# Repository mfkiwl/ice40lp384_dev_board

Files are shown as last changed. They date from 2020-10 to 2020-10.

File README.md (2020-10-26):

The ice30lp384_dev_board project is a multi-purpose castellated board that can be used in a breadboard or as a module in other projects.

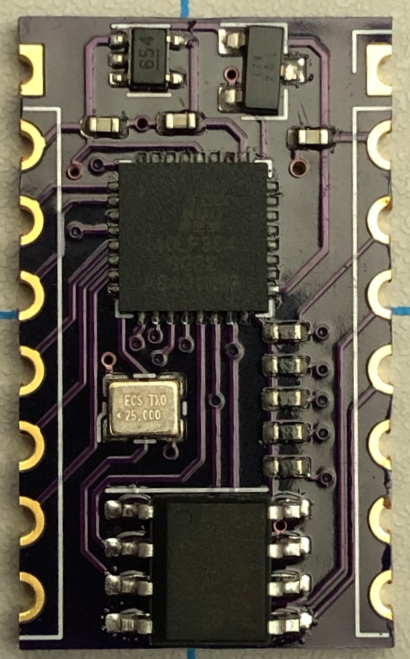
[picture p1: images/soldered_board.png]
main


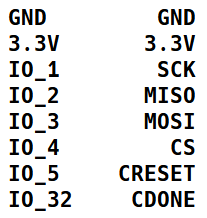
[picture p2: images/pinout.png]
pinout


- [Programming](/docs/Programming.md)
- [Board Creation](/docs/Board_Creation.md)

The pins on the right side of the board are geared towards programming and the pins on the left are for general use.

PCBs were ordered from OSHPark.
Stencil was ordered from OSHStencil.
Parts were ordered from Mouser, see [BOM](/docs/BOM%20-Mouser%20.xlsx).

The constraint files can be found [here](/verilog_projects/config).

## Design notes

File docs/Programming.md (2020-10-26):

To program the SPI Flash you need to hold the FPGA in reset when powering up the board. To do this, you need to connect CRESET to GND. You can install a button or switch if you plan to do this often or just use a jumper wire.

Here is an example setup using a push-button connected to CRESET.
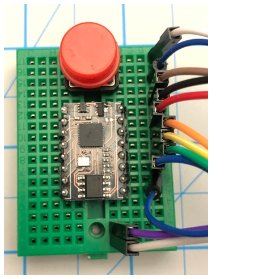
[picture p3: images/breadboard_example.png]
Breadboard Example


I use a [SPIDriver](https://spidriver.com/) to program the SPI Flash. There are dozens of alternative options. If you are on Linux then check out the [Flashrom supported programmers](https://flashrom.org/Supported_programmers).

A minimal programming connection needs the following lines hooked-up:

- GND to GND
- 3.3V to 3.3V
- SCK to SCK
- MISO to MISO
- MOSI to MOSI
- CS to CS
- CRESET to GND

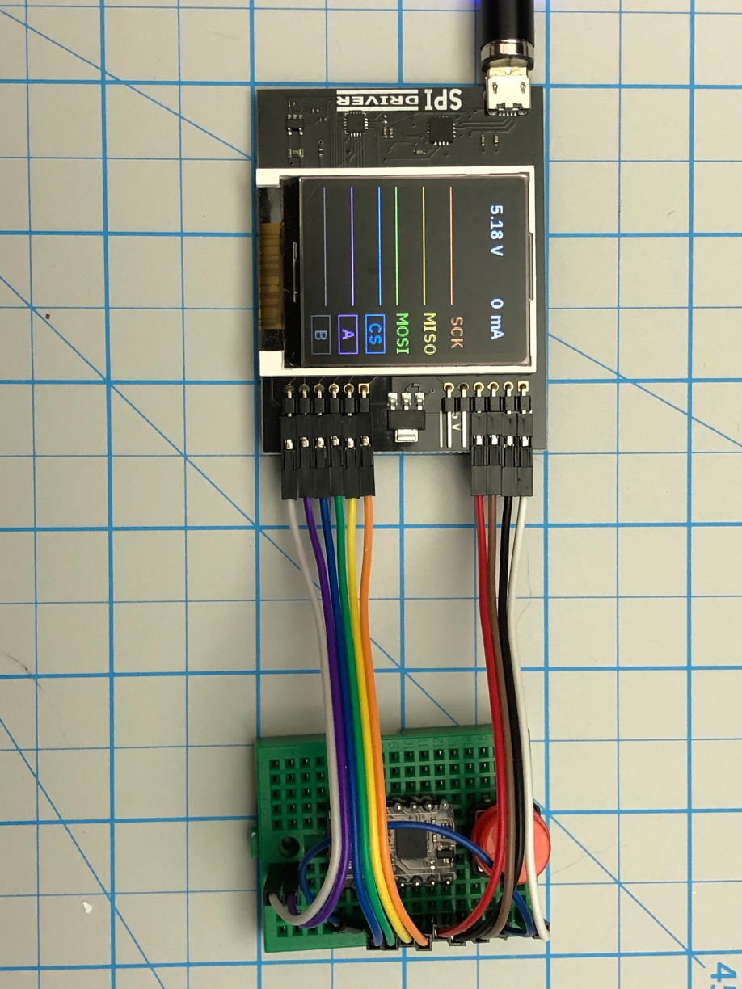
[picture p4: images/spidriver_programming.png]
SPIDriver Programming


Useful SPIDriver Commands:
```
# Read JEDEC
python flash.py -h COM3

# Write BIN file
python flash.py -h COM3 -w data\main_bitmap.bin
```

Programming with flashrom command on linux:
```
# Pad a file to 128k to match the size of the flash
tr '\0' '\377' < /dev/zero | dd bs=1 count=131072 of=image.bin

# Combine bitmap and padded file
dd if=blinky_bitmap.bin conv=notrunc of=image.bin

# Write padded bitmap file to SPI Flash
sudo flashrom -p ft2232_spi:type=232H -w image.bin
```

Note: Configuring the FPGA logic and setting up a develpment environment is outside the scope of this project. I recommend [NandLand](https://www.nandland.com/) for a great general purpose development board and in-depth tutorials if you are new to FPGAs. If you end up using IceCube2 with this board then make sure you [configure the project](/images/new_project_config.png) appropriately.

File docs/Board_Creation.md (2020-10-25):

# Board Creation

### PCB Front
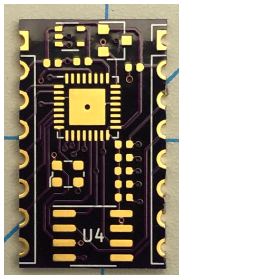
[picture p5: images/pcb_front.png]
PCB Front


### PCB Back
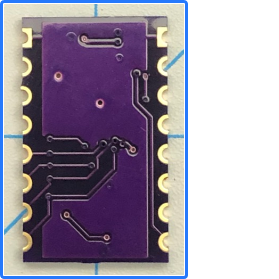
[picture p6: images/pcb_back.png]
PCB Back


### Stencil Alignment
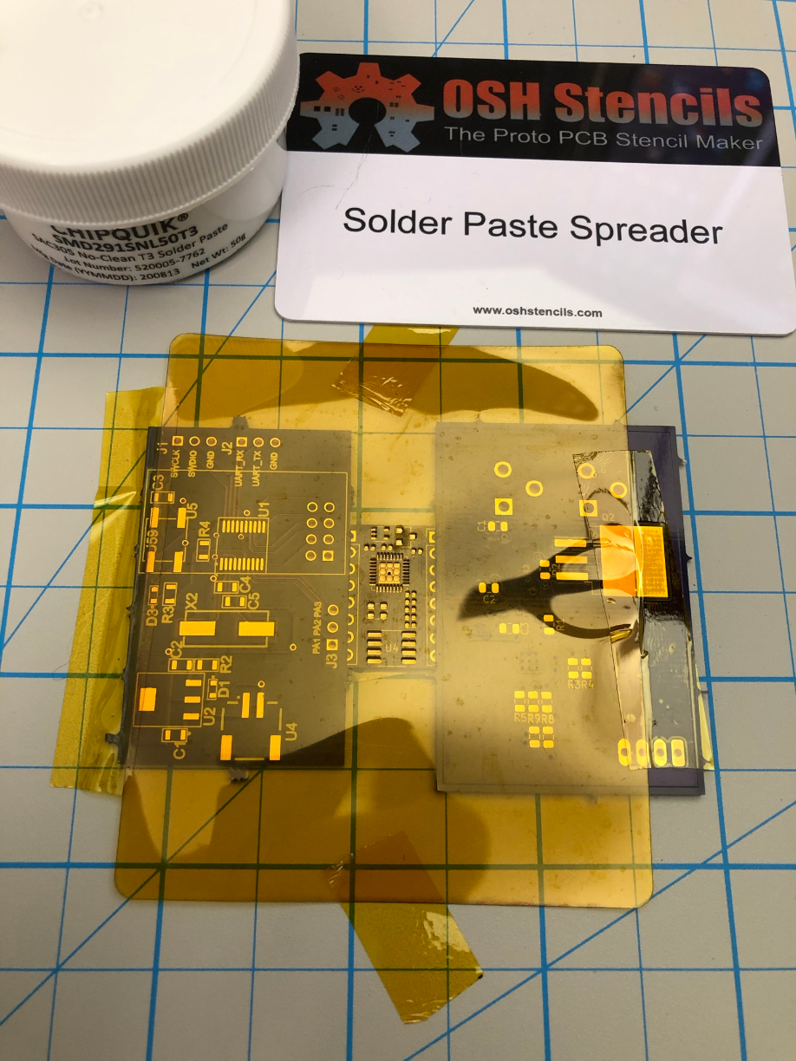
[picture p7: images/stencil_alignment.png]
Stencil Alignment


### Solder Paste
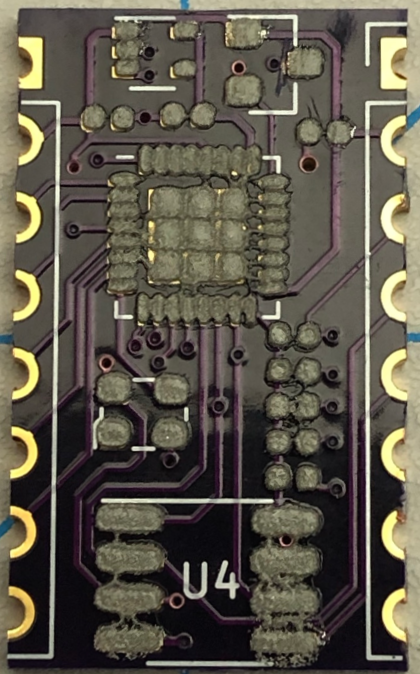
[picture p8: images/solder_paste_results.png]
Solder Paste Results


### Part Placement
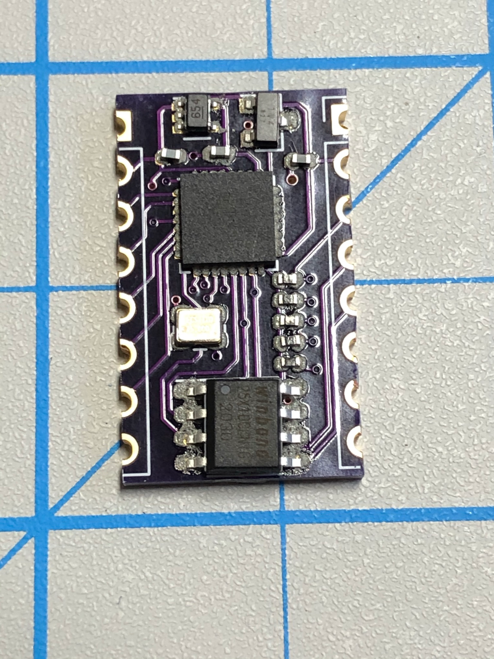
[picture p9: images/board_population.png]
Part Placement


### Reflow using Hot Plate. 
I use a cast iron skillet on a Hot Plate. Set the temperature dial to medium and remove boards when solder has melted ~5 mins.
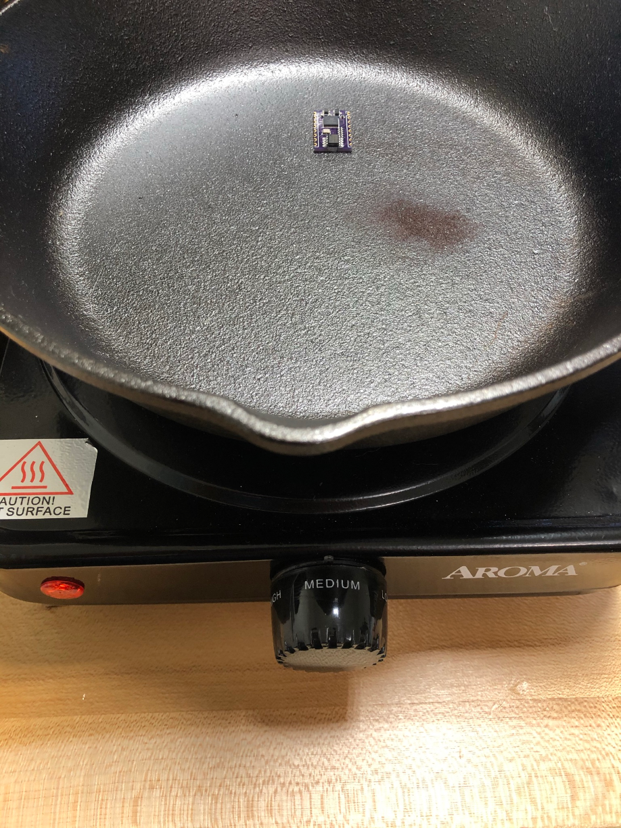
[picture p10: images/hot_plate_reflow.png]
Hot Plate Reflow


### Soldered Board
Soldered Board

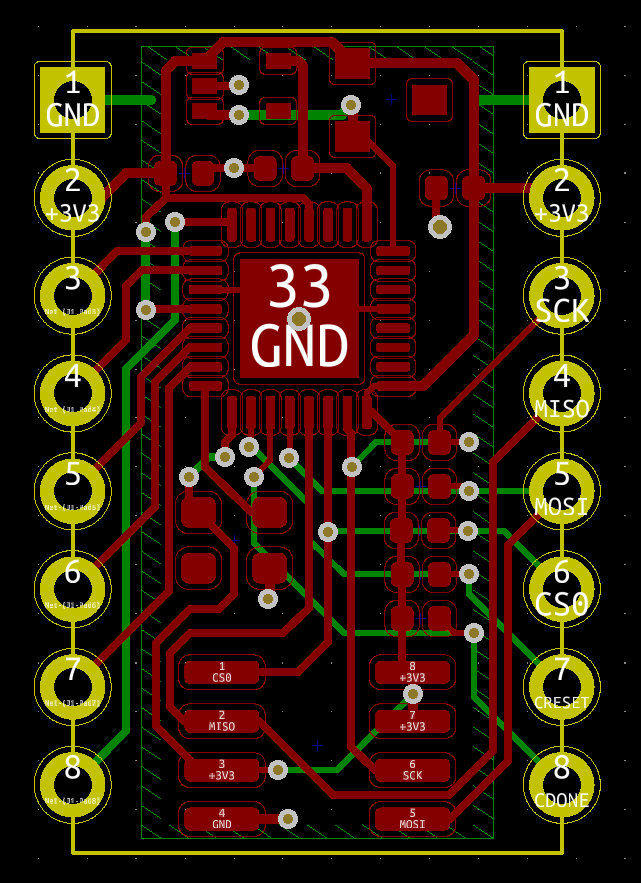
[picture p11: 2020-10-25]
images/layout_high_level.png

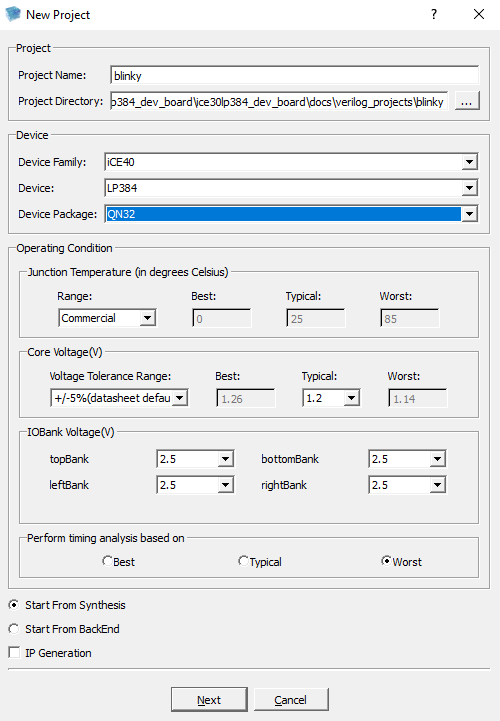
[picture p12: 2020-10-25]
images/new_project_config.png

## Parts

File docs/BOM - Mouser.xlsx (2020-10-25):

Mfr Part Number (Input) | Quantity 1 | Mfr Part Number | Mouser Part Number | Manufacturer Name | Description | Unit Price 1 | Order Quantity | Order Unit Price | Min./Mult. | Availability | Lead Time in Days | Lead Time in Weeks | Lifecycle | NCNR | RoHS | Pb Free | Package Type | Package Quantity | Datasheet URL | Product Image | Design Risk
998-MIC5365-1.2YC5TR | 1 | MIC5365-1.2YC5-TR | 998-MIC5365-1.2YC5TR | Microchip | LDO Voltage Regulators LDO Voltage Regulators Ultra Small Single 150mA LDO | $0.12 | 1 | $0.12 | 1\1 | 13,269 | 56 | 8 |  | No | Yes | Yes | REEL | 3,000 | https://www.mouser.com/datasheet/2/268/mic5365-1082359.pdf |  | Product has high popularity and is readily available.
757-TBAT54SLM | 1 | TBAT54S,LM | 757-TBAT54SLM | Toshiba | Schottky Diodes & Rectifiers Schottky Diodes & Rectifiers Small-Signal Schotky 0.2A 30V | $0.21 | 1 | $0.21 | 1\1 | 5,175 | 77 | 11 |  | No | Yes | Yes | REEL | 3,000 | https://toshiba.semicon-storage.com/info/docget.jsp?did=66549&prodName=TBAT54S |  | Product has high popularity and is readily available.
842-ICE40LP384SG32 | 1 | ICE40LP384-SG32 | 842-ICE40LP384SG32 | Lattice | FPGA - Field Programmable Gate Array FPGA - Field Programmable Gate Array iCE40LP Ultra LowPwr 384 LUTs 1.2V | $1.51 | 1 | $1.51 | 1\1 | 1,364 | 45 | 7 |  | No | Yes | Yes | TRAY | 490 | https://www.mouser.com/datasheet/2/225/FPGA-DS-02029-3-5-iCE40-LP-HX-Family-Data-Sheet-1022803.pdf |  | Product has high popularity and is readily available.
454-W25X10CLSNIG | 1 | W25X10CLSNIG | 454-W25X10CLSNIG | Winbond | NOR Flash NOR Flash spiFlash, 1M-bit, 4Kb Uniform Sector | $0.31 | 1 | $0.31 | 1\1 | 5,438 | 30 | 5 |  | No | Yes | Yes | TUBE | 2,000 | https://www.mouser.com/datasheet/2/949/w25x10cl_revg_021714-1489755.pdf |  | Product has high popularity and is readily available.
963-EMK105BJ105MVHF | 3 | EMK105BJ105MVHF | 963-EMK105BJ105MVHF | Taiyo Yuden | Multilayer Ceramic Capacitors MLCC - SMD/SMT Multilayer Ceramic Capacitors MLCC - SMD/SMT 0402 16VDC 1uF 20% X5R AEC-Q200 | $0.10 | 3 | $0.10 | 1\1 | 57,265 | 112 | 16 | New Product | No | Yes | Yes | REEL | 10,000 | https://www.mouser.com/datasheet/2/396/taiyo_yuden_12132018_mlcc11_hq_e-1510082.pdf |  | Product is new and is readily available.
603-RC0402FR-0710KL | 5 | RC0402FR-0710KL | 603-RC0402FR-0710KL | Yageo | Thick Film Resistors - SMD Thick Film Resistors - SMD 10K OHM 1% | $0.10 | 5 | $0.10 | 1\1 | 23,214,044 | 161 | 23 |  | No | Yes | No | REEL | 10,000 | https://www.mouser.com/catalog/additional/Yageo_6012_CM_Statement.pdf |  | Product has high popularity and is readily available.
538-22-28-4080 | 1 | 22-28-4080 | 538-22-28-4080 | Molex | Headers & Wire Housings Headers & Wire Housings 8P VERT HEADER Sn | $0.35 | 1 | $0.35 | 1\1 | 2,976 | 28 | 4 |  | No | Yes | Yes | BULK | 6,000 | https://www.mouser.com/catalog/additional/Molex.pdf |  | Product has high popularity and is readily available.
520-2520MV-250-BN-T | 1 | ECS-2520MV-250-BN-TR | 520-2520MV-250-BN-T | ECS | Standard Clock Oscillators Standard Clock Oscillators 25MHz 1.6-3.6V -40C +85C | $0.96 | 1 | $0.96 | 1\1 | 3,019 | 84 | 12 |  | No | Yes | Yes | REEL | 3,000 | https://www.mouser.com/datasheet/2/122/ECS-2520MV-1314080.pdf |  | Product has high popularity and is readily available.

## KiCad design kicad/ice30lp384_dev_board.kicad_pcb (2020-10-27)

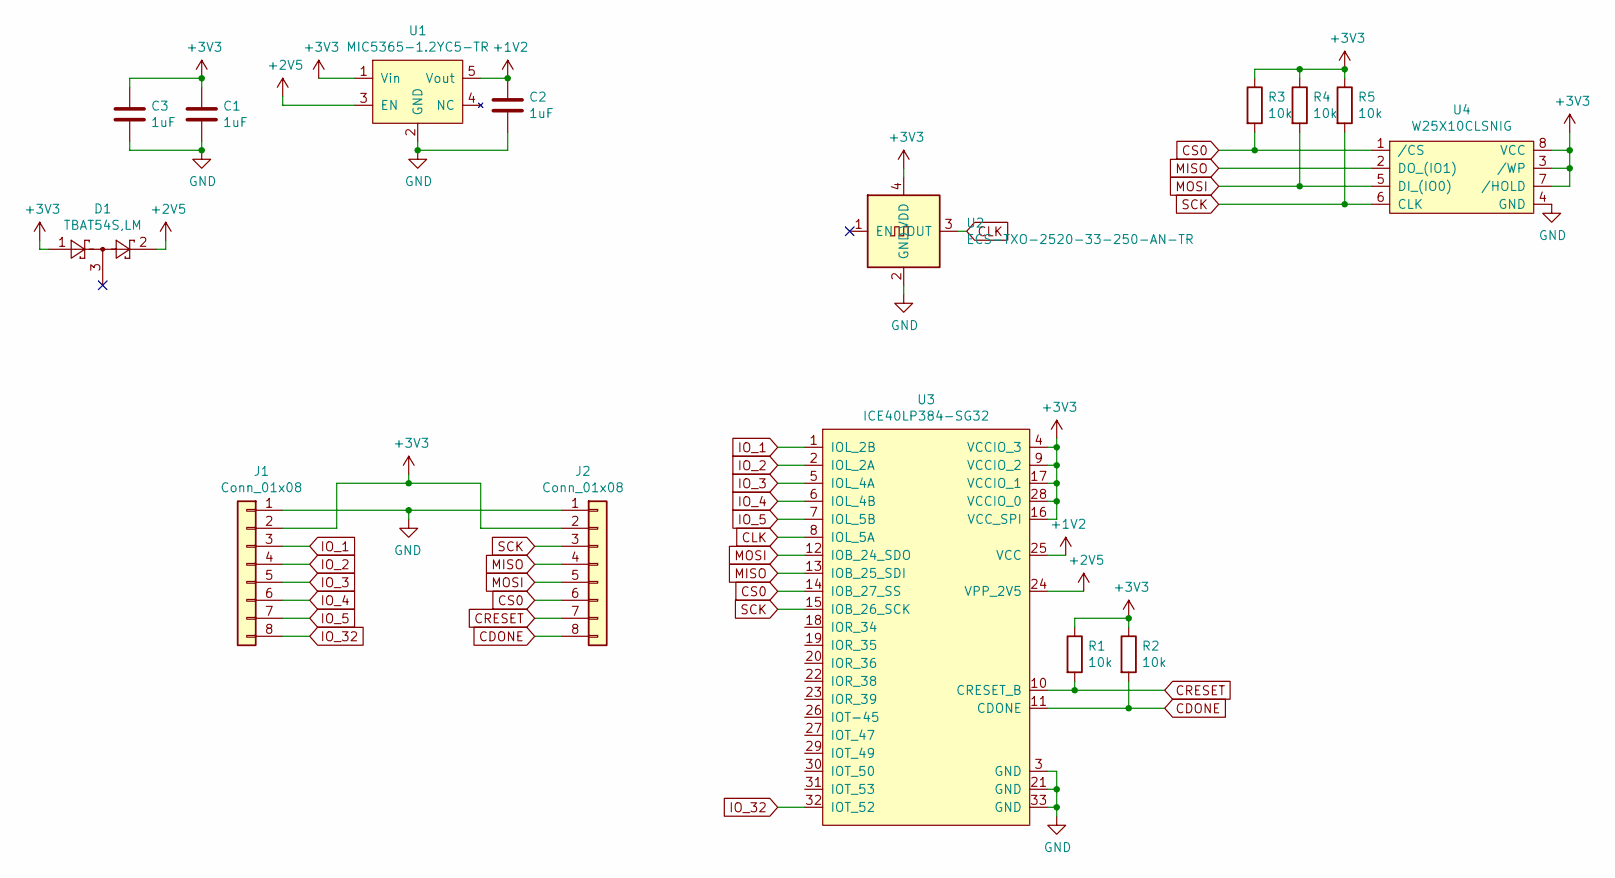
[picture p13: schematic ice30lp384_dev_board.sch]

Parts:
C1, C2, C3: 1uF; C_0402_1005Metric
D1: TBAT54S,LM; SOT-23
J1, J2: Conn_01x08; PinHeader_1x08_P2.54mm_Vertical
R1, R2, R3, R4, R5: 10k; R_0402_1005Metric
U1: MIC5365-1.2YC5-TR; SOT-353_SC-70-5
U2: ECS-TXO-2520-33-250-AN-TR; Oscillator_SMD_ECS_2520MV-xxx-xx-4Pin_2.5x2.0mm
U3: ICE40LP384-SG32; QFN-32-1EP_5x5mm_P0.5mm_EP3.1x3.1mm
U4: W25X10CLSNIG; SOIC-8_3.9x4.9mm_P1.27mm

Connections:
+1V2: C2.1, U1.5 (Vout), U3.25 (VCC)
+2V5: D1.2, U1.3 (EN), U3.24 (VPP_2V5)
+3V3: C1.1, C3.1, D1.1, J1.2, J2.2, R1.1, R2.1, R3.1, R4.1, R5.1, U1.1 (Vin), U2.4 (VDD), U3.4 (VCCIO_3), U3.9 (VCCIO_2), U3.16 (VCC_SPI), U3.17 (VCCIO_1), U3.28 (VCCIO_0), U4.3 (/WP), U4.7 (/HOLD), U4.8 (VCC)
CDONE: J2.8, R2.2, U3.11 (CDONE)
CLK: U2.3 (OUT), U3.8 (IOL_5A)
CRESET: J2.7, R1.2, U3.10 (CRESET_B)
CS0: J2.6, R3.2, U3.14 (IOB_27_SS), U4.1 (/CS)
GND: C1.2, C2.2, C3.2, J1.1, J2.1, U1.2 (GND), U2.2 (GND), U3.3 (GND), U3.21 (GND), U3.33 (GND), U4.4 (GND)
IO_1: J1.3, U3.1 (IOL_2B)
IO_2: J1.4, U3.2 (IOL_2A)
IO_3: J1.5, U3.5 (IOL_4A)
IO_4: J1.6, U3.6 (IOL_4B)
IO_5: J1.7, U3.7 (IOL_5B)
IO_32: J1.8, U3.32 (IOT_52)
MISO: J2.4, U3.13 (IOB_25_SDI), U4.2 (DO_(IO1))
MOSI: J2.5, R4.2, U3.12 (IOB_24_SDO), U4.5 (DI_(IO0))
SCK: J2.3, R5.2, U3.15 (IOB_26_SCK), U4.6 (CLK)

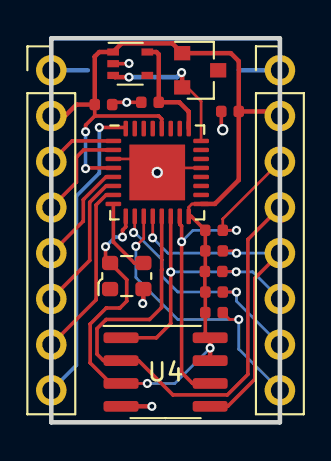
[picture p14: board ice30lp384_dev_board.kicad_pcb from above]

Board: 2 copper layers, 12.7 x 21.3 mm, 15 parts (0 on the bottom side), 17 nets.

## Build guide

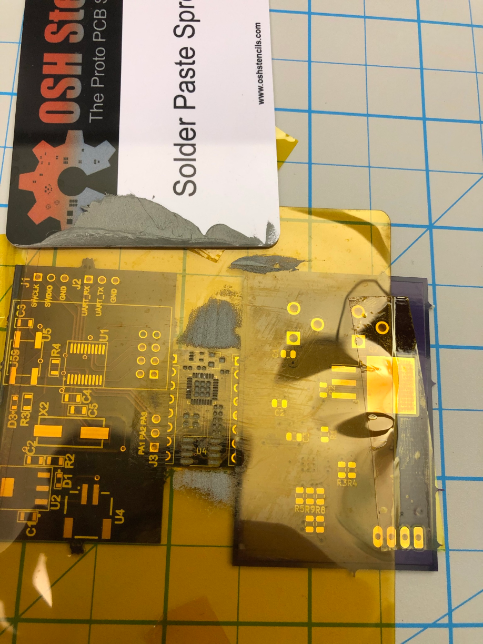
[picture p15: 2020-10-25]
images/solder_paste_application.png

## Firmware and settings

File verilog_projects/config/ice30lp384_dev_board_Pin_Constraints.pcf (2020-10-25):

# ##############################################################################

# iCEcube PCF

# File Generated:     Sept 27 2020 09:46:33

# Family & Device:    iCE40LP384

# Package:            QFN32

# ##############################################################################

### Main FPGA Clock
set_io i_Clk 8

### General IO:
set_io io_1 1
set_io io_2 2
set_io io_3 5
set_io io_4 6
set_io io_5 7
set_io io_7 32

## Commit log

2020-10-19 Removed ground connection from 2.5V Diode
    Updated files to change ground connection to no-connection for 2.5v diode. v1.0 boards have cut traces to prevent short to ground.
    [ice30lp384_dev_board-B_Cu.gbr, ice30lp384_dev_board-B_Mask.gbr, ice30lp384_dev_board-B_Paste.gbr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]
2020-10-25 Added Documentation
    Added documentation and cleaned up project structure.
    No board changes were made.
    [BOM - Mouser.xlsx, ice30lp384_dev_board.kicad_pcb, ice30lp384_dev_board.sch]
2020-10-27 Improved castellation compatibility
    Improved compatibility with OshPark's castellation rules which involved changing all pin header pads to be round.
    Cleaned up schematic.
    [ice30lp384_dev_board-B_Cu.gbr, ice30lp384_dev_board-B_Mask.gbr, ice30lp384_dev_board-B_Paste.gbr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]
